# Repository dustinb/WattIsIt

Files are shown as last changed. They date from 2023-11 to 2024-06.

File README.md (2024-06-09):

# Camp Sense

Camp Sense connects to WattIsIt via bluetooth and displays the energy and weather data. The `App` folder contains
the React Native app developed using Expo.

| Energy | Weather |
| :---: | :---: |
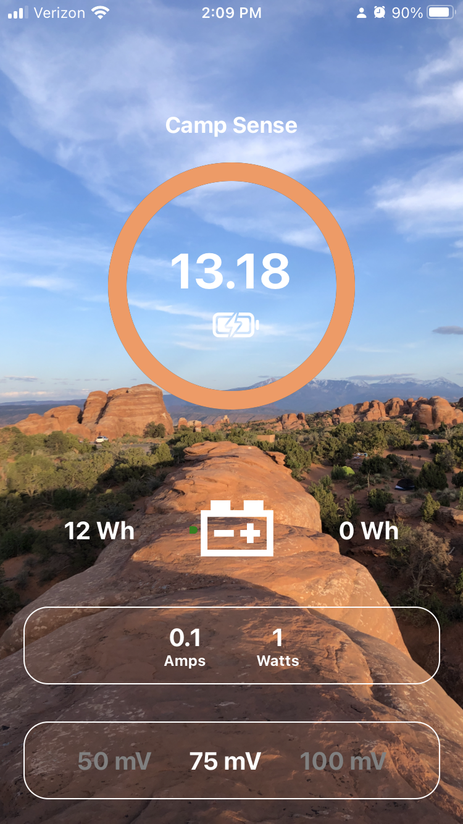
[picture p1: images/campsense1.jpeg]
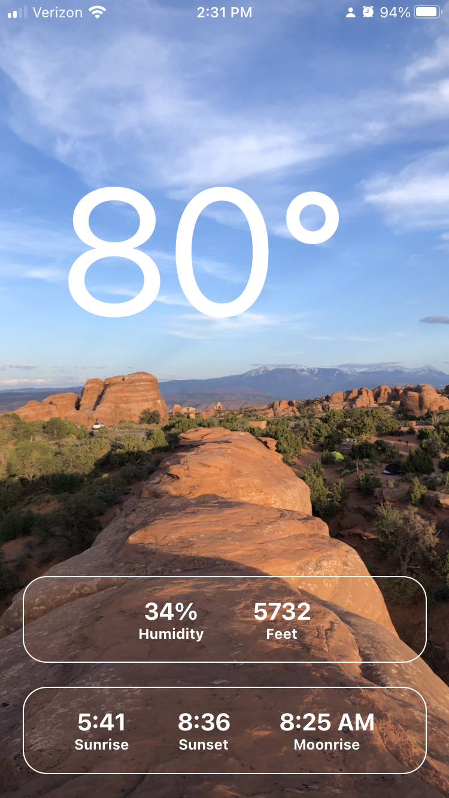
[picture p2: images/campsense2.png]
|  |  |

# WattIsIT

A battery watt meter using ADS1115 and a shunt to measure power usage. There are 2 Arduino sketches, `Arduino/RemoteXY` and `Arduino/Camp Sense`. The latter uses Platform IO plugin for VSCode and works with the Camp Sense app.

## BOM

AHT21 is optional, was used for humidity but also has a temperature sensor.

| Item | Link |
| --- | --- |
| U2 ESP32 | https://a.co/d/88cG9Z5 |
| M1 ADS1115 | https://a.co/d/gfCO6jt |
| U1 Voltage Reg | https://a.co/d/cpmFpuU |
| U4 AHT21 | https://a.co/d/6xBWBLx |
| U3 BMP280 | https://a.co/d/1HV9oyw |
| J1 Terminals | https://a.co/d/8nVocXb |
| Shunt | https://a.co/d/7QWWK5O |
| R1 10k Ohm | https://a.co/d/6f4wvqz |
| R2 5k Ohm | https://a.co/d/adCeki6 |

## Version 1.0

| KiCad Model | In Use |
| :---: | :---: |
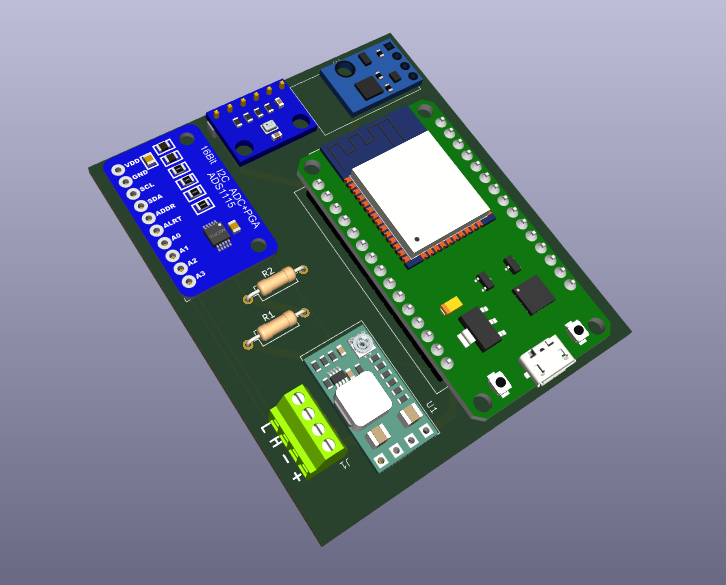
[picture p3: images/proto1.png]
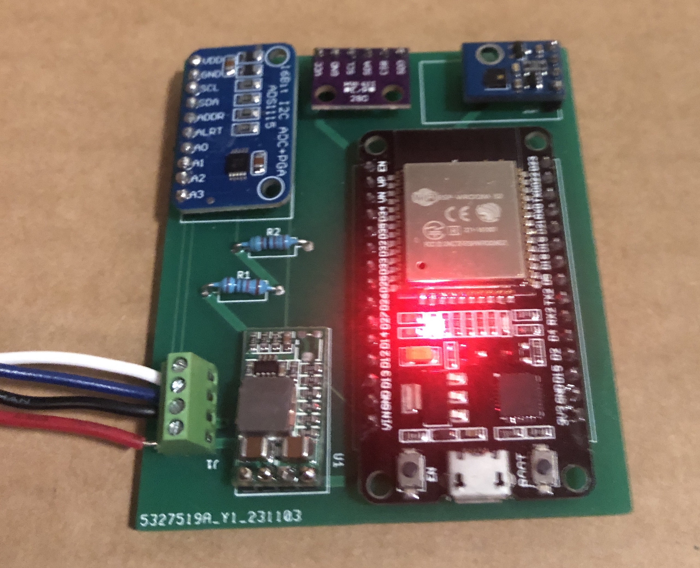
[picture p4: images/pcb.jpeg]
|  |  |

## Screw Connections

\+ 12 volt + \
\- 12 volt - \
L Low side of shunt \
H High side of shunt

## Remote XY

Before the Camp Sense app Remote XY was used for development. The sketch is in `Arduino/RemoteXY`.

The Remote XY is a free app is used to view data with bluetooh. This also has a setting for the shunt 50, 75, or 100 mV. The setting is persisted in eeprom (flash memory)

https://remotexy.com/en/editor/391325040dffc13fc4e74f019a2b24ee/

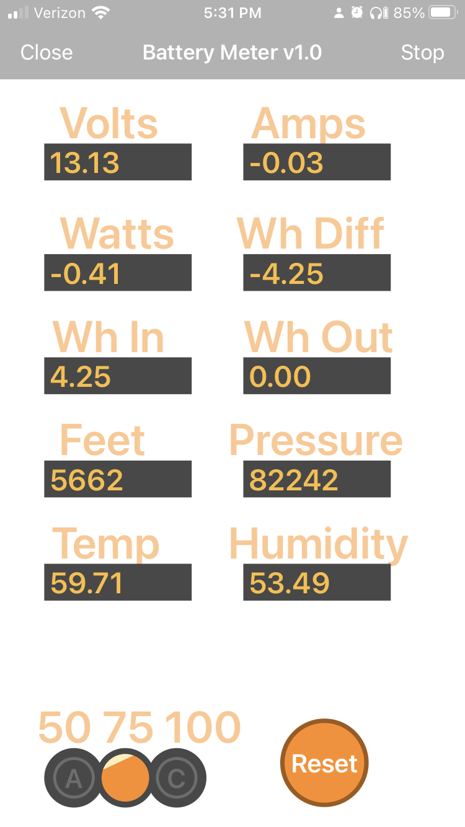
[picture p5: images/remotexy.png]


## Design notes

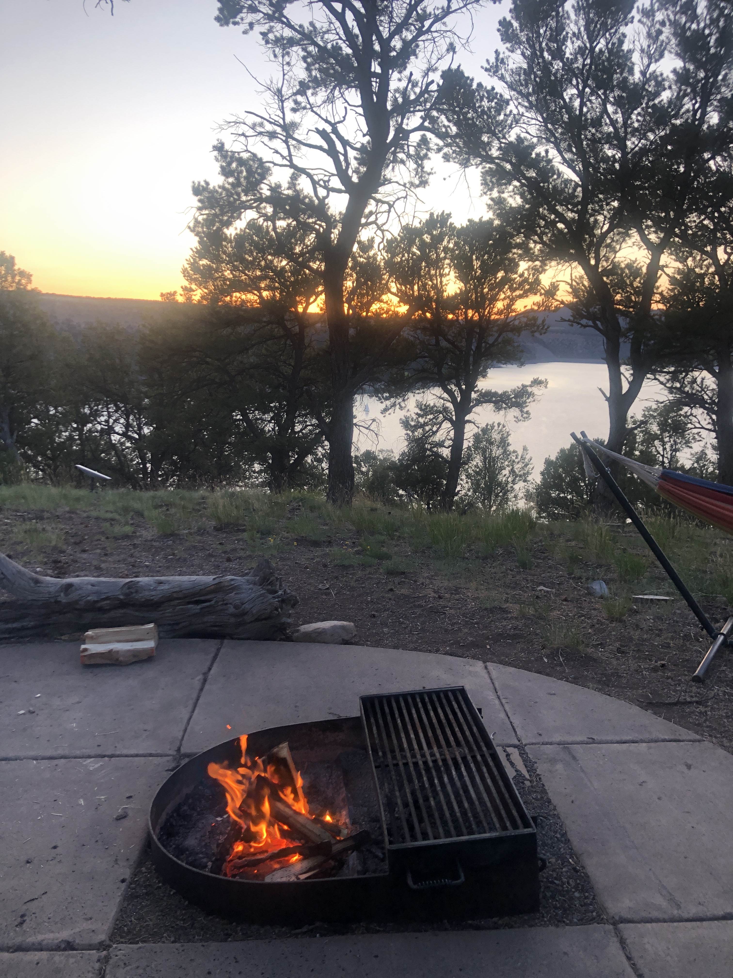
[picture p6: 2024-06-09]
App/assets/camp2.jpg

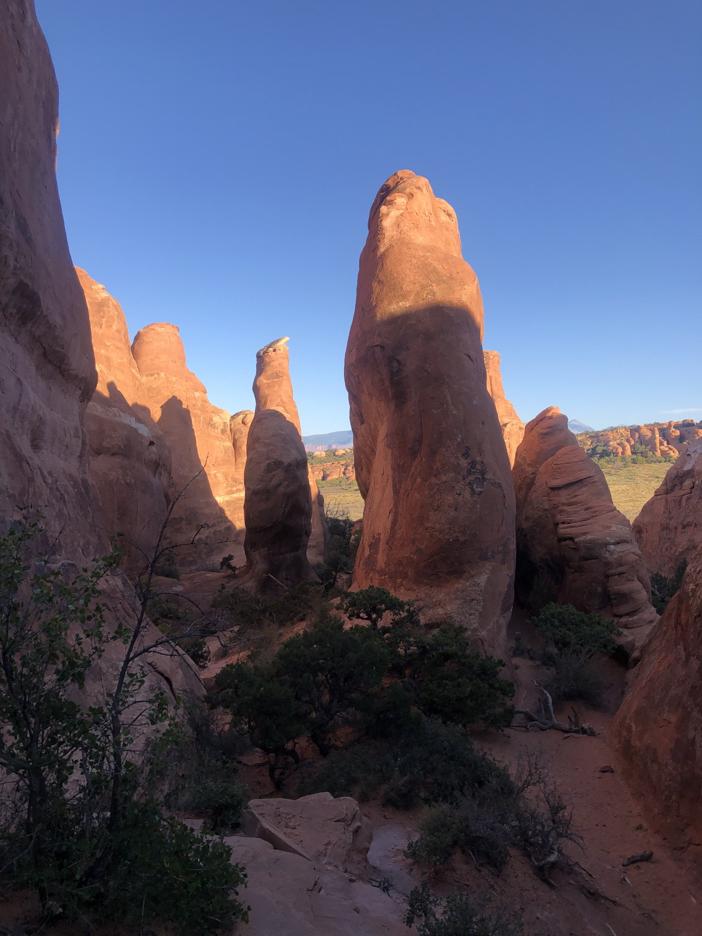
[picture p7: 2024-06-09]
App/assets/camp5.jpg

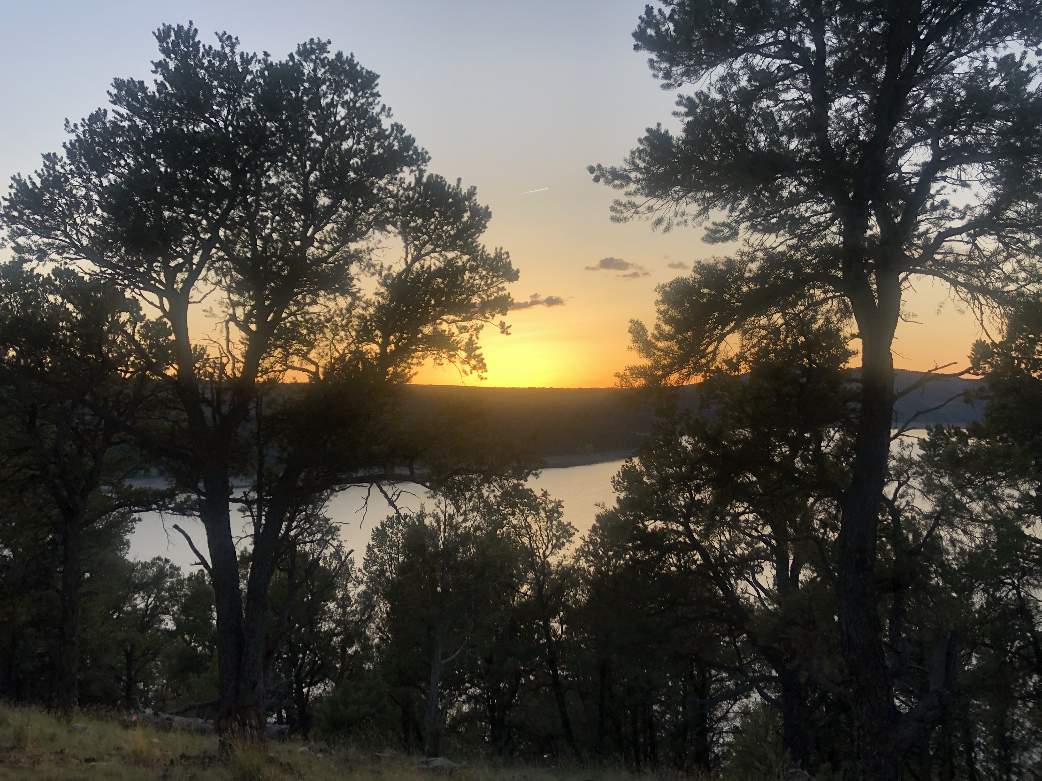
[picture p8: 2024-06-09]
App/assets/camp3.jpg

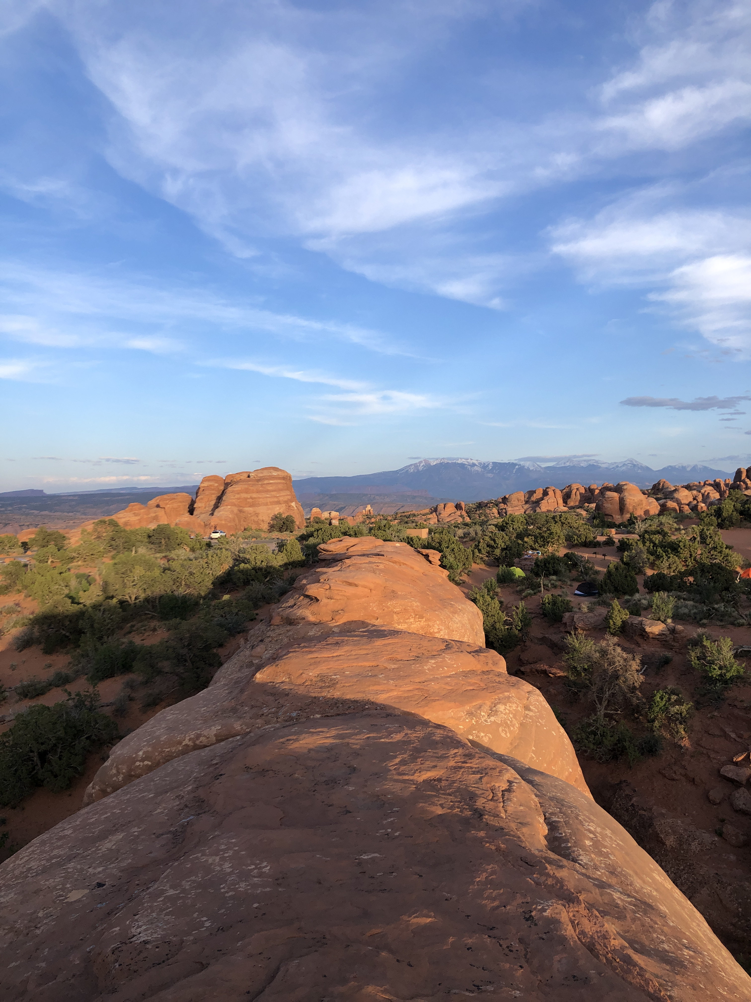
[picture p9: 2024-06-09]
App/assets/camp4.jpg

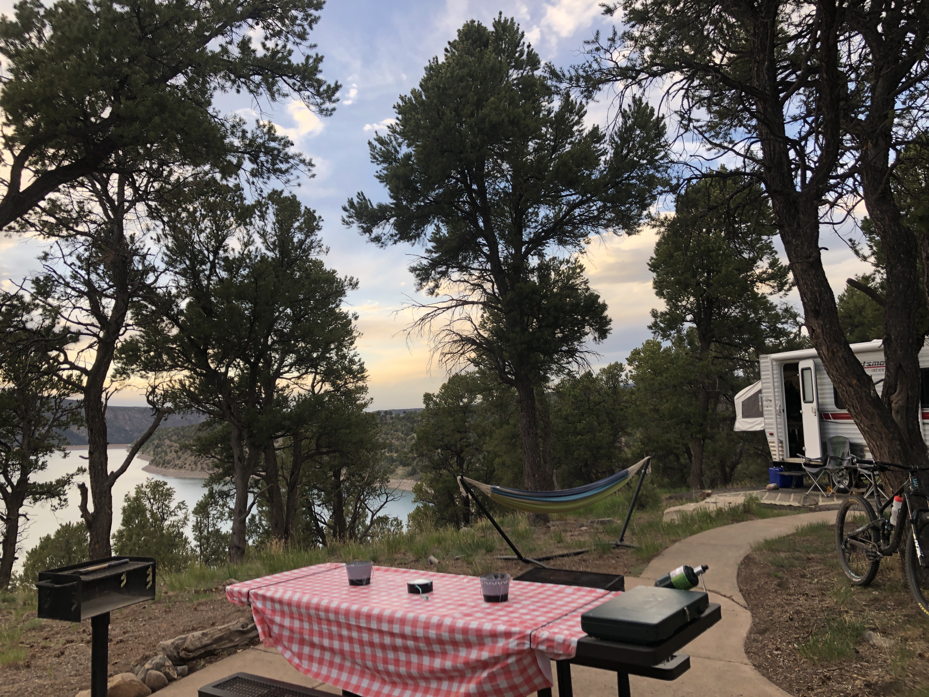
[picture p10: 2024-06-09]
App/assets/camp1.jpg

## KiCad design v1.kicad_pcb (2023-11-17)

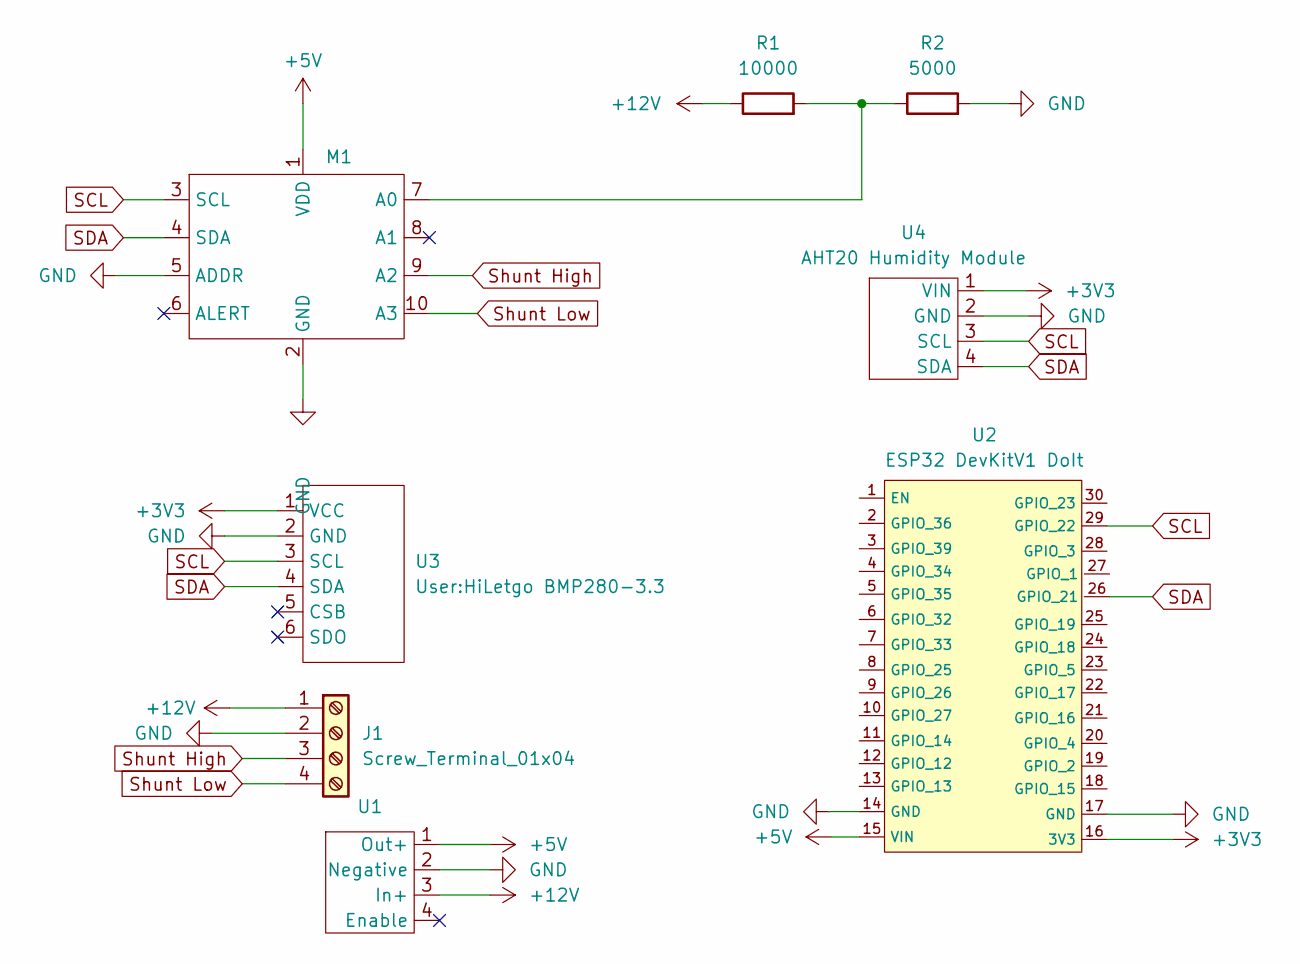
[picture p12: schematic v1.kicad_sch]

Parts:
J1: Screw_Terminal_01x04; Screw Terminal 2.54 x4
M1: ADS1115
R1: 10000; R_Axial_DIN0207_L6.3mm_D2.5mm_P10.16mm_Horizontal
R2: 5000; R_Axial_DIN0207_L6.3mm_D2.5mm_P10.16mm_Horizontal
U1: Drok Vreg
U2: ESP32 DevKitV1 DoIt
U3: HiLetgo BMP280-3.3
U4: AHT20 Humidity Module

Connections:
+3V3: U2.16 (3V3), U3.1 (VCC), U4.1 (VIN)
+5V: M1.1 (VDD), U1.1 (Out+), U2.15 (VIN)
+12V: J1.1, R1.1, U1.3 (In+)
GND: J1.2, M1.2 (GND), M1.5 (ADDR), R2.2, U1.2 (Negative), U2.14 (GND), U2.17 (GND), U3.2 (GND), U4.2 (GND)
unnamed: M1.7 (A0), R1.2, R2.1
SCL: M1.3 (SCL), U2.29 (GPIO_22), U3.3 (SCL), U4.3 (SCL)
SDA: M1.4 (SDA), U2.26 (GPIO_21), U3.4 (SDA), U4.4 (SDA)
Shunt High: J1.3, M1.9 (A2)
Shunt Low: J1.4, M1.10 (A3)

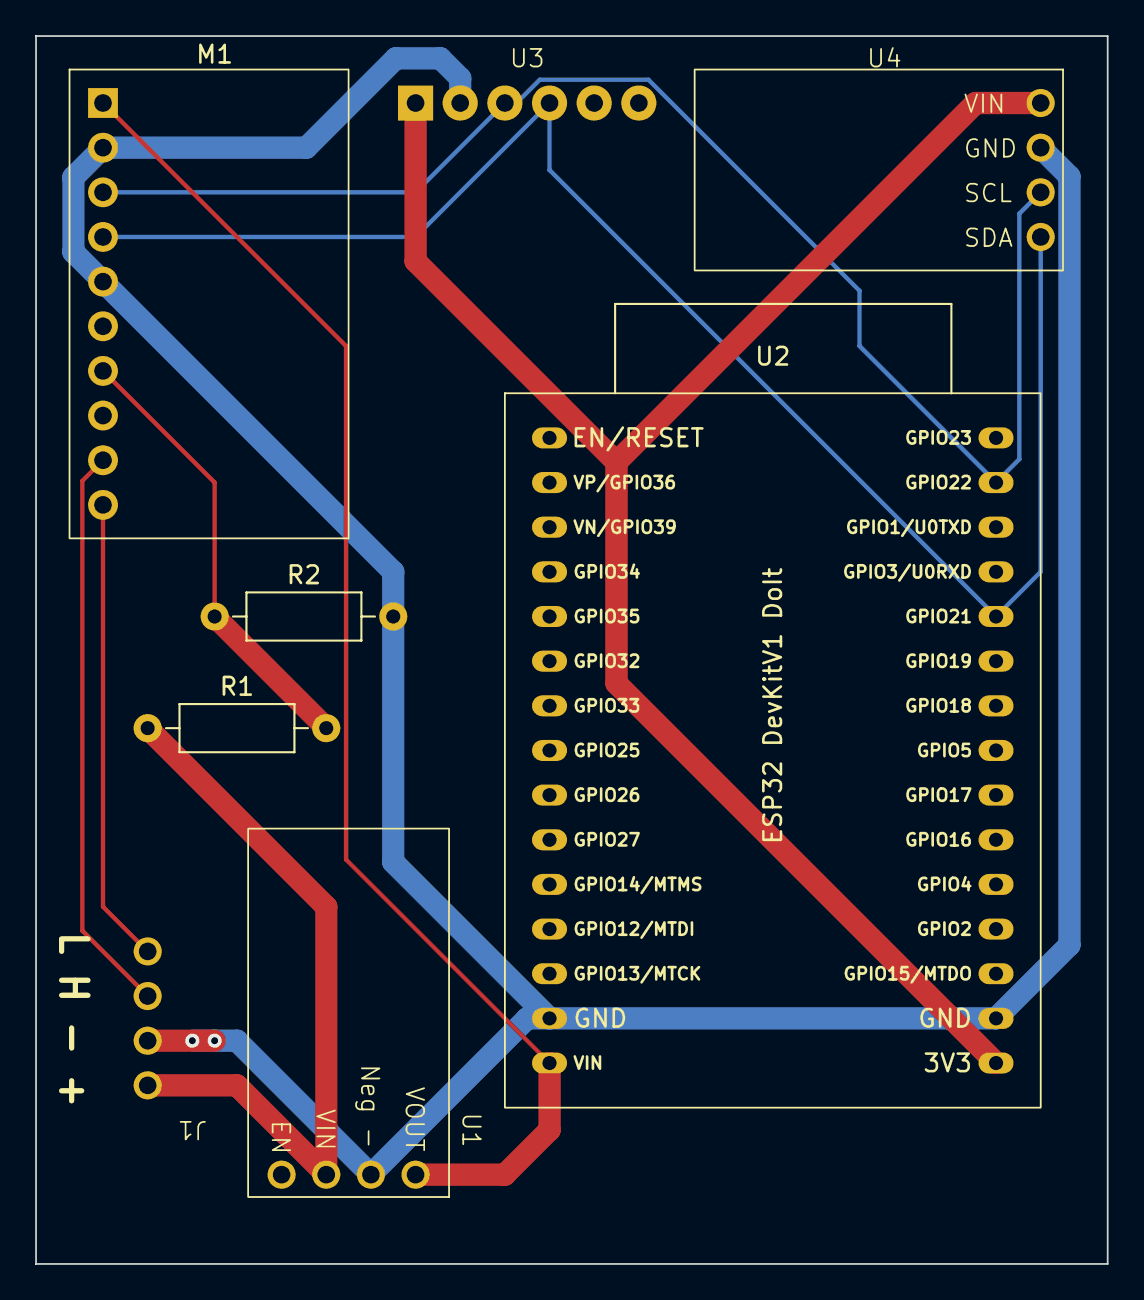
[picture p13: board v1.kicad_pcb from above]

Board: 2 copper layers, 61.0 x 69.8 mm, 8 parts (0 on the bottom side), 9 nets.

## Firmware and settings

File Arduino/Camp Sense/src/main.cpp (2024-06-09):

#include <Arduino.h>

#include <EEPROM.h>
#include <BLEDevice.h>
#include <BLEServer.h>
#include <BLEUtils.h>
#include <BLE2902.h>

#define DEVICE_NAME "WattIsIt"

#define SERVICE_UUID "13030a97-68c2-4746-852a-3566bce33d89"
#define CHAR_UUID_WEATHER_DATA "eb19820c-c6cc-46a8-93a6-3645803d8e8f"
#define CHAR_UUID_ENERGY_DATA "1dc27998-20cd-4cf5-a5f3-3fe25f55c0f8"
#define CHAR_UUID_MV "6ebe8ad1-ab57-4f57-bf64-fd9ce197d9c4"

BLECharacteristic *pWeatherDataChar;
BLECharacteristic *pEnergyDataChar;
BLECharacteristic *pMvDataChar;

// #define BMP
#ifdef BMP
#include <Adafruit_BMP085.h>
Adafruit_BMP085 bmp;
#endif

#define ADC
#ifdef ADC
#include "ADS1X15.h"
ADS1115 ADS(0x48);
#endif

#define BMP280
#ifdef BMP280
#include "Adafruit_BMP280.h"
Adafruit_BMP280 bmp280;
#endif

#define AHT2x
#ifdef AHT2x
#include <AHT20.h>
AHT20 aht20;
#endif

float wattHoursCharge = 0;
float wattHoursDischarge = 0;
unsigned long lastADCRead = 0;
uint8_t mVSetting = 1;

class BaseBLEServerCallbacks : public BLEServerCallbacks
// Callback triggered when a client device connects or disconnects
{
  void onConnect(BLEServer *pServer)
  {
    Serial.println("Device connected");
  }

  void onDisconnect(BLEServer *pServer)
  {
    // Restart advertising
    Serial.println("Device disconnected");
    BLEAdvertising *pAdvertising = pServer->getAdvertising();
    if (pAdvertising)
    {
      pAdvertising->start();
    }
  }
};

// Got a new mV setting and/or reset request
class mvCallback : public BLECharacteristicCallbacks
{
  void onWrite(BLECharacteristic *pCharacteristic)
  {
    std::string value = pCharacteristic->getValue();
    uint16_t newMV = (value[1] << 8) | value[0];
    uint16_t reset = (value[3] << 8) | value[2];
    if (newMV != mVSetting)
    {
      Serial.print("Setting mV to: ");
      Serial.println(newMV);
      mVSetting = newMV;
      EEPROM.write(0, mVSetting);
      EEPROM.commit();
    }
    if (reset > 0)
    {
      Serial.println("Resetting watt hours");
      wattHoursCharge = 0;
      wattHoursDischarge = 0;
    }
  }
};

void setup()
{
  Serial.begin(115200);

#ifdef ADC
  ADS.begin();
#endif

#ifdef BMP
  bmp.begin();
#endif

#ifdef BMP280
  bmp280.begin(0x76, 0x58);
#endif

#ifdef AHT2x
  aht20.begin();
#endif

  EEPROM.begin(1); // Initialize EEPROM 1 bytes
  uint8_t eepromValue = EEPROM.read(0);
  if (eepromValue > 2)
  {
    // Default to 75mv if no value
    mVSetting = 1;
  }
  else
  {
    mVSetting = eepromValue;
  }

  lastADCRead = millis();

  // Create BLE server, and characteristics
  BLEDevice::init(DEVICE_NAME);

  BLEServer *pServer = BLEDevice::createServer();
  pServer->setCallbacks(new BaseBLEServerCallbacks());

  BLEService *pService = pServer->createService(SERVICE_UUID);

  pEnergyDataChar = pService->createCharacteristic(
      CHAR_UUID_ENERGY_DATA,
      BLECharacteristic::PROPERTY_READ | BLECharacteristic::PROPERTY_NOTIFY);
  pEnergyDataChar->addDescriptor(new BLE2902());

  pWeatherDataChar = pService->createCharacteristic(
      CHAR_UUID_WEATHER_DATA,
      BLECharacteristic::PROPERTY_READ | BLECharacteristic::PROPERTY_NOTIFY);
  pWeatherDataChar->addDescriptor(new BLE2902());

  pMvDataChar = pService->createCharacteristic(
      CHAR_UUID_MV,
      BLECharacteristic::PROPERTY_READ | BLECharacteristic::PROPERTY_WRITE);
  pMvDataChar->addDescriptor(new BLE2902());
  pMvDataChar->setCallbacks(new mvCallback());
  pMvDataChar->setValue(&mVSetting, mVSetting);

  // Start BLE server and advertising
  pService->start();
  BLEAdvertising *pAdvertising = BLEDevice::getAdvertising();
  pAdvertising->addServiceUUID(SERVICE_UUID);
  pAdvertising->setScanResponse(true);
  pAdvertising->setMinPreferred(0x06);
  pAdvertising->setMinPreferred(0x12);
  BLEDevice::startAdvertising();
  Serial.println("BLE device is ready to be connected");
}

void loop()
{

  struct WeatherData
  {
    float temperature;
    float humidity;
    float pressure;
    float altitude;
  };

  struct EnergyData
  {
    float volts;
    float amps;
    float wattHoursIn;
    float wattHoursOut;
  };

  WeatherData weather;
  EnergyData energyData;

  int notifyDelay = 500;
  float temp = 0;
  float tempCount = 0;

#ifdef BMP
  temp += bmp.readTemperature();
  tempCount++;
  weather.pressure = bmp.readPressure();
  weather.altitude = bmp.readAltitude() * 3.28084;
#endif

#ifdef BMP280
  temp += bmp280.readTemperature();
  tempCount++;
  weather.pressure = bmp280.readPressure();
  weather.altitude = bmp280.readAltitude() * 3.28084;

  Serial.print("Altitude: ");
  Serial.println(weather.altitude);
  Serial.print("Pressure: ");
  Serial.println(weather.pressure);
#endif

#ifdef AHT2x
  if (aht20.available() == true)
  {
    // Get the new temperature and humidity value
    temp += aht20.getTemperature();
    tempCount++;
    weather.humidity = aht20.getHumidity();

    Serial.print("Humidity: ");
    Serial.println(weather.humidity);

    // The AHT20 can respond with a reading every ~50ms. However, increased read time can cause the IC to heat around 1.0C above ambient.
    // The datasheet recommends reading every 2 seconds.
    delay(200);
  }
#endif

#ifdef ADC
  ADS.setGain(0);
  int16_t adc = ADS.readADC(0);
  float f = ADS.toVoltage(1);
  float adcVolts = adc * f;

  // Resister values measured
  int R1 = 9880;
  int R2 = 5100;

  // https://ohmslawcalculator.com/voltage-divider-calculator
  float vbat = ((R1 + R2) * adcVolts) / R2;
  energyData.volts = vbat;
  Serial.print("Voltage: ");
  Serial.println(vbat);

  // Differential shunt current
  // https://learnarduinonow.com/2015/05/11/reading-current-shunt-with-arduino.html
  int16_t results;
  ADS.setGain(16);
  unsigned long currentTime = millis();
  results = ADS.readADC_Differential_2_3();
  unsigned long delta = currentTime - lastADCRead;
  lastADCRead = millis();

  float amps = ((float)results * 256.0) / 32768.0; // 100mv shunt
  if (mVSetting == 1)
  {
    amps = amps * 1.333; // 75mv shunt
  }
  if (mVSetting == 0)
  {
    amps = amps * 2; // 50mv shunt
  }
  energyData.amps = amps;
  Serial.print("Amps: ");
  Serial.println(amps);

  float power = amps * vbat;
  float energy = (power * delta) / (3600.0 * 1000.0); // Convert milliseconds to hours

  if (energy < 0)
  {
    wattHoursCharge += energy * -1.0;
  }
  else
  {
    wattHoursDischarge += energy;
  }

  Serial.print("Watt Hours In: ");
  Serial.println(wattHoursCharge);
  energyData.wattHoursIn = wattHoursCharge;

  Serial.print("Watt Hours Out: ");
  Serial.println(wattHoursDischarge);
  energyData.wattHoursOut = wattHoursDischarge;
#endif

  // Average temp of all sensors
  if (tempCount > 0)
  {
    weather.temperature = temp / tempCount;
    Serial.print("Temp: ");
    Serial.println(weather.temperature);
  }

  // Pack the data into a byte array
  uint8_t weatherDataBytes[sizeof(WeatherData)];
  memcpy(weatherDataBytes, &weather, sizeof(WeatherData));
  pWeatherDataChar->setValue(weatherDataBytes, sizeof(WeatherData));
  pWeatherDataChar->notify();

  uint8_t energyDataBytes[sizeof(EnergyData)];
  memcpy(energyDataBytes, &energyData, sizeof(EnergyData));
  pEnergyDataChar->setValue(energyDataBytes, sizeof(EnergyData));
  pEnergyDataChar->notify();

  delay(1500);
}

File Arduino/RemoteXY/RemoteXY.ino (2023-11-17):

#include <EEPROM.h>

// #define BMP
#ifdef BMP
  #include <Adafruit_BMP085.h>
  Adafruit_BMP085 bmp;
#endif

#define ADC
#ifdef ADC
  #include "ADS1X15.h"
  ADS1115 ADS(0x48);
#endif

#define BMP280
#ifdef BMP280
  #include "Adafruit_BMP280.h"
  Adafruit_BMP280 bmp280;
#endif

#define AHT2x
#ifdef AHT2x
  #include <AHT20.h>
  AHT20 aht20;
#endif

//////////////////////////////////////////////
//        RemoteXY include library          //
//////////////////////////////////////////////

// RemoteXY select connection mode and include library 
#define REMOTEXY_MODE__ESP32CORE_BLE
#include <BLEDevice.h>

#include <RemoteXY.h>

// RemoteXY connection settings 
#define REMOTEXY_BLUETOOTH_NAME "Battery Meter v1.0"


// RemoteXY configurate  
#pragma pack(push, 1)
uint8_t RemoteXY_CONF[] =   // 275 bytes
  { 255,2,0,110,0,12,1,16,31,1,129,0,7,59,18,6,17,84,101,109,
  112,0,67,4,6,65,20,5,2,26,11,129,0,8,45,18,6,17,70,101,
  101,116,0,67,4,6,51,20,5,2,26,11,129,0,31,45,25,6,17,80,
  114,101,115,115,117,114,101,0,67,4,33,51,20,5,2,26,11,129,0,8,
  2,18,6,17,86,111,108,116,115,0,67,4,6,8,20,5,2,26,11,129,
  0,8,17,16,6,17,87,97,116,116,115,0,67,4,6,23,20,5,2,26,
  11,129,0,31,59,25,6,17,72,117,109,105,100,105,116,121,0,67,4,33,
  65,20,5,2,26,11,129,0,34,2,18,6,17,65,109,112,115,0,67,4,
  33,8,20,5,2,26,11,129,0,7,31,18,6,17,87,104,32,73,110,0,
  67,4,6,37,20,5,2,26,11,129,0,33,31,21,6,17,87,104,32,79,
  117,116,0,67,4,33,37,20,5,2,26,11,129,0,32,17,21,6,17,87,
  104,32,68,105,102,102,0,67,4,33,23,20,5,2,26,11,1,0,38,86,
  12,12,2,31,82,101,115,101,116,0,3,131,6,90,22,8,2,26,129,0,
  5,84,26,6,17,53,48,32,55,53,32,49,48,48,0 };
  
// this structure defines all the variables and events of your control interface 
struct {

    // input variables
  uint8_t reset; // =1 if button pressed, else =0 
  uint8_t mV; // =0 if select position A, =1 if position B, =2 if position C, ... 

    // output variables
  char temp[11];  // string UTF8 end zero 
  char altitude[11];  // string UTF8 end zero 
  char pressure[11];  // string UTF8 end zero 
  char volts[11];  // string UTF8 end zero 
  char watts[11];  // string UTF8 end zero 
  char humidity[11];  // string UTF8 end zero 
  char amps[11];  // string UTF8 end zero 
  char charge[11];  // string UTF8 end zero 
  char discharge[11];  // string UTF8 end zero 
  char watts_diff[11];  // string UTF8 end zero 

    // other variable
  uint8_t connect_flag;  // =1 if wire connected, else =0 

} RemoteXY;
#pragma pack(pop)

/////////////////////////////////////////////
//           END RemoteXY include          //
/////////////////////////////////////////////


float wattHoursCharge = 0;
float wattHoursDischarge = 0;
unsigned long lastADCRead = 0;
uint8_t lastSetting = 1;

void setup() 
{
  pinMode(LED_BUILTIN, OUTPUT);
  Serial.begin(115200);
  #ifdef ADC
    ADS.begin();
  #endif

  #ifdef BMP
    bmp.begin();
	#endif

  #ifdef BMP280
    bmp280.begin(0x76, 0x58);
	#endif

  #ifdef AHT2x
    aht20.begin();
  #endif

  
  EEPROM.begin(1);  // Initialize EEPROM 1 bytes
  uint8_t eepromValue = EEPROM.read(0);
  if (eepromValue > 2) {
    // Default to 75mv if no value
    lastSetting = 1;
  } else {
    lastSetting = eepromValue;
  }
  
  RemoteXY_Init ();
  // Initialize the mV selector 50, 75, or 100 mv
  RemoteXY.mV = lastSetting;
  
  lastADCRead = millis();
}

void loop() 
{ 

  float temp = 0;
  float tempCount = 0;

  #ifdef BMP
    temp += (bmp.readTemperature() * 9/5) + 32;
    tempCount++;
    float pressure = bmp.readPressure();
    float altitude = bmp.readAltitude() * 3.28084;

    dtostrf(altitude, 1, 0, RemoteXY.altitude);
    dtostrf(pressure, 1, 0, RemoteXY.pressure);
  #endif

  #ifdef BMP280
    temp += (bmp280.readTemperature() * 9/5) + 32;
    tempCount++;
    float pressure = bmp280.readPressure();
    float altitude = bmp280.readAltitude() * 3.28084;

    dtostrf(altitude, 1, 0, RemoteXY.altitude);
    dtostrf(pressure, 1, 0, RemoteXY.pressure);
  #endif

  #ifdef AHT2x
    if (aht20.available() == true) {
      //Get the new temperature and humidity value
      temp += (aht20.getTemperature() * 9/5) + 32;
      tempCount++;
      float humidity = aht20.getHumidity();
      dtostrf(humidity, 1, 2, RemoteXY.humidity);
      //The AHT20 can respond with a reading every ~50ms. However, increased read time can cause the IC to heat around 1.0C above ambient.
      //The datasheet recommends reading every 2 seconds.  RemoteXY doesn't want any delay though.
      delay(200);
    }
  #endif

  #ifdef ADC
    ADS.setGain(0);
    int16_t adc = ADS.readADC(0);
    float f = ADS.toVoltage(1);
    float adcVolts = adc * f;

    // Resister values measured
    int R1 = 9880;
    int R2 = 5000;
   
    // https://ohmslawcalculator.com/voltage-divider-calculator
    float vbat = ((R1 + R2) * adcVolts) / R2;
    dtostrf(vbat, 1, 2, RemoteXY.volts);
    
    // Differential shunt current
    // https://learnarduinonow.com/2015/05/11/reading-current-shunt-with-arduino.html
    int16_t results;
    ADS.setGain(16);
    unsigned long currentTime = millis(); 
    results = ADS.readADC_Differential_2_3();
    unsigned long delta = currentTime - lastADCRead;
    lastADCRead = millis();

    float amps = ((float)results * 256.0) / 32768.0; // 100mv shunt
    if (RemoteXY.mV == 1) {
      amps = amps * 1.333; // 75mv shunt
    }
    if (RemoteXY.mV == 0) {
      amps = amps * 2; // 50mv shunt
    }  
    
    float power = amps * vbat;
    float energy = (power * delta) / (3600.0 * 1000.0);  // Convert milliseconds to hours

    if (energy < 0) {
      wattHoursCharge += energy * -1.0;
    } else {
      wattHoursDischarge += energy;
    }

    dtostrf(power, 1, 2, RemoteXY.watts);
    dtostrf(amps, 1, 2, RemoteXY.amps);
    dtostrf(wattHoursCharge, 1, 2, RemoteXY.charge);
    dtostrf(wattHoursDischarge, 1, 2, RemoteXY.discharge);
    dtostrf(wattHoursDischarge - wattHoursCharge, 1, 2, RemoteXY.watts_diff);
  #endif

  // Average temp of all sensors
  dtostrf(temp / tempCount, 1, 2, RemoteXY.temp);

  if (RemoteXY.reset == 1) {
    wattHoursCharge = 0;
    wattHoursDischarge = 0;
  }
  
  if (RemoteXY.mV != lastSetting) {
    lastSetting = RemoteXY.mV;
    EEPROM.write(0, lastSetting);
    EEPROM.commit();
  }

  RemoteXY_Handler();
  // TODO you loop code
  // use the RemoteXY structure for data transfer
  // do not call delay() 
}
